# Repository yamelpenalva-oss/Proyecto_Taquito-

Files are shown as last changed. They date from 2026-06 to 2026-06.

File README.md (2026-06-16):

# Robot Futbolista Autónomo

---

## Institución

Escuela de Educación Secundaria Técnica N° 5  
“2 de Abril” – Temperley – Buenos Aires

---

## Materia

Montajes de Proyectos Electrónicos

---

## Grupo

Taquito

---

## Autores

Nuñez, Ian — naikalo2000@gmail.com  
Guerra, Marcos — marcoscolegio3@gmail.com  
Penalva, Yamel — yamelpenalva@gmail.com  

---

## Profesor

Ing. Martín Leguizamón

---

## Descripción del proyecto

El presente proyecto consiste en el desarrollo de un robot futbolista autónomo, diseñado para participar en ligas nacionales de robótica.

El sistema integra hardware y software para permitir un comportamiento autónomo capaz de interactuar con el entorno en tiempo real, mediante la detección de la pelota, posicionamiento en el campo de juego y toma de decisiones.

El control del robot se realiza a través de microcontroladores ESP32 programados , aplicando principios de programación embebida.

---

## Objetivos

- Desarrollar un robot autónomo orientado a competencias de fútbol robótico  
- Integrar sensores, actuadores y microcontroladores  
- Implementar lógica de control en tiempo real  
- Aplicar conocimientos de electrónica y programación  
- Lograr un sistema funcional y eficiente  

---

## Materiales utilizados

- Motores de corriente continua (x4)  
- Módulo WiFi/Bluetooth  
- Microcontroladores ESP32 (x2)  
- Controladores de motor (TN6612 o TA6586)  

---

## Tecnologías y herramientas

- Lenguaje: C++ (framework Arduino / ESP32)  
- Entorno de desarrollo: Arduino IDE  
- Comunicación: WiFi y Bluetooth  
- Control de motores mediante PWM  
- Lectura de sensores digitales y analógicos  

---

## Lógica del sistema

El funcionamiento del robot se basa en una arquitectura de control que incluye:

- Lectura continua de sensores  
- Procesamiento de datos en tiempo real  
- Toma de decisiones mediante estructuras condicionales  
- Control de actuadores en función del entorno  

El comportamiento general contempla estrategias de búsqueda, ataque y corrección de trayectoria.

---

## Funcionamiento

El firmware desarrollado permite:

- Controlar el movimiento del robot  
- Procesar información del entorno  
- Ejecutar estrategias de juego  
- Adaptarse a condiciones variables durante la competencia  

El código se encuentra estructurado de forma modular, facilitando su mantenimiento y escalabilidad.

---

## Estado del proyecto

- Sistema funcional  
- Integración de hardware completa  
- Control de motores implementado  
- Proyecto en mejora continua  

---

## Mejoras futuras

- Optimización del sistema de detección de pelota  
- Mejora en la precisión de movimiento  
- Implementación de comunicación entre módulos  
- Desarrollo de estrategias más avanzadas  

---

## Enfoque de ingeniería

El proyecto fue desarrollado con un enfoque práctico, orientado a su implementación en entornos reales de competencia, priorizando:

- Robustez del sistema  
- Simplicidad en la lógica de control  
- Eficiencia en el uso de recursos  
- Claridad en la estructura del código  

---

## preguntas 

-Ante cualquier consulta o inconveniente, comuníquese con Yamel Penalva a través de Gmail.

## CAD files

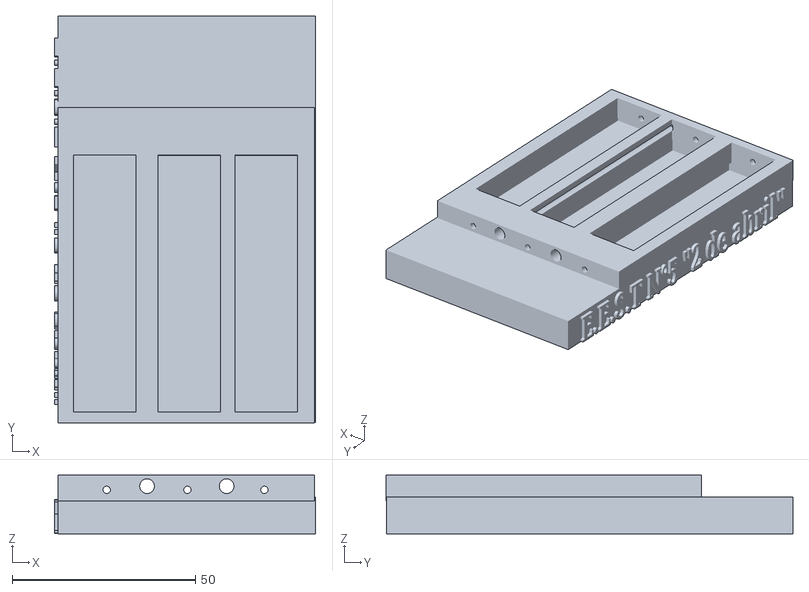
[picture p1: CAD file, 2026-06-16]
diseño3D/porta pilas.stl
71.3 x 111.0 x 16.0

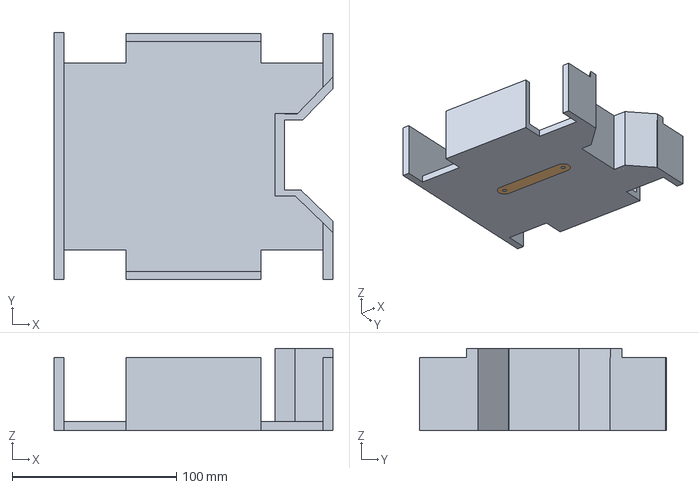
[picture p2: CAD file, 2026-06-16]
diseño3D/futbolista diseño 3d.3mf
170.0 x 150.5 x 50.0 mm
Futbolista Seba.stl_1
Futbolista Seba.stl_2

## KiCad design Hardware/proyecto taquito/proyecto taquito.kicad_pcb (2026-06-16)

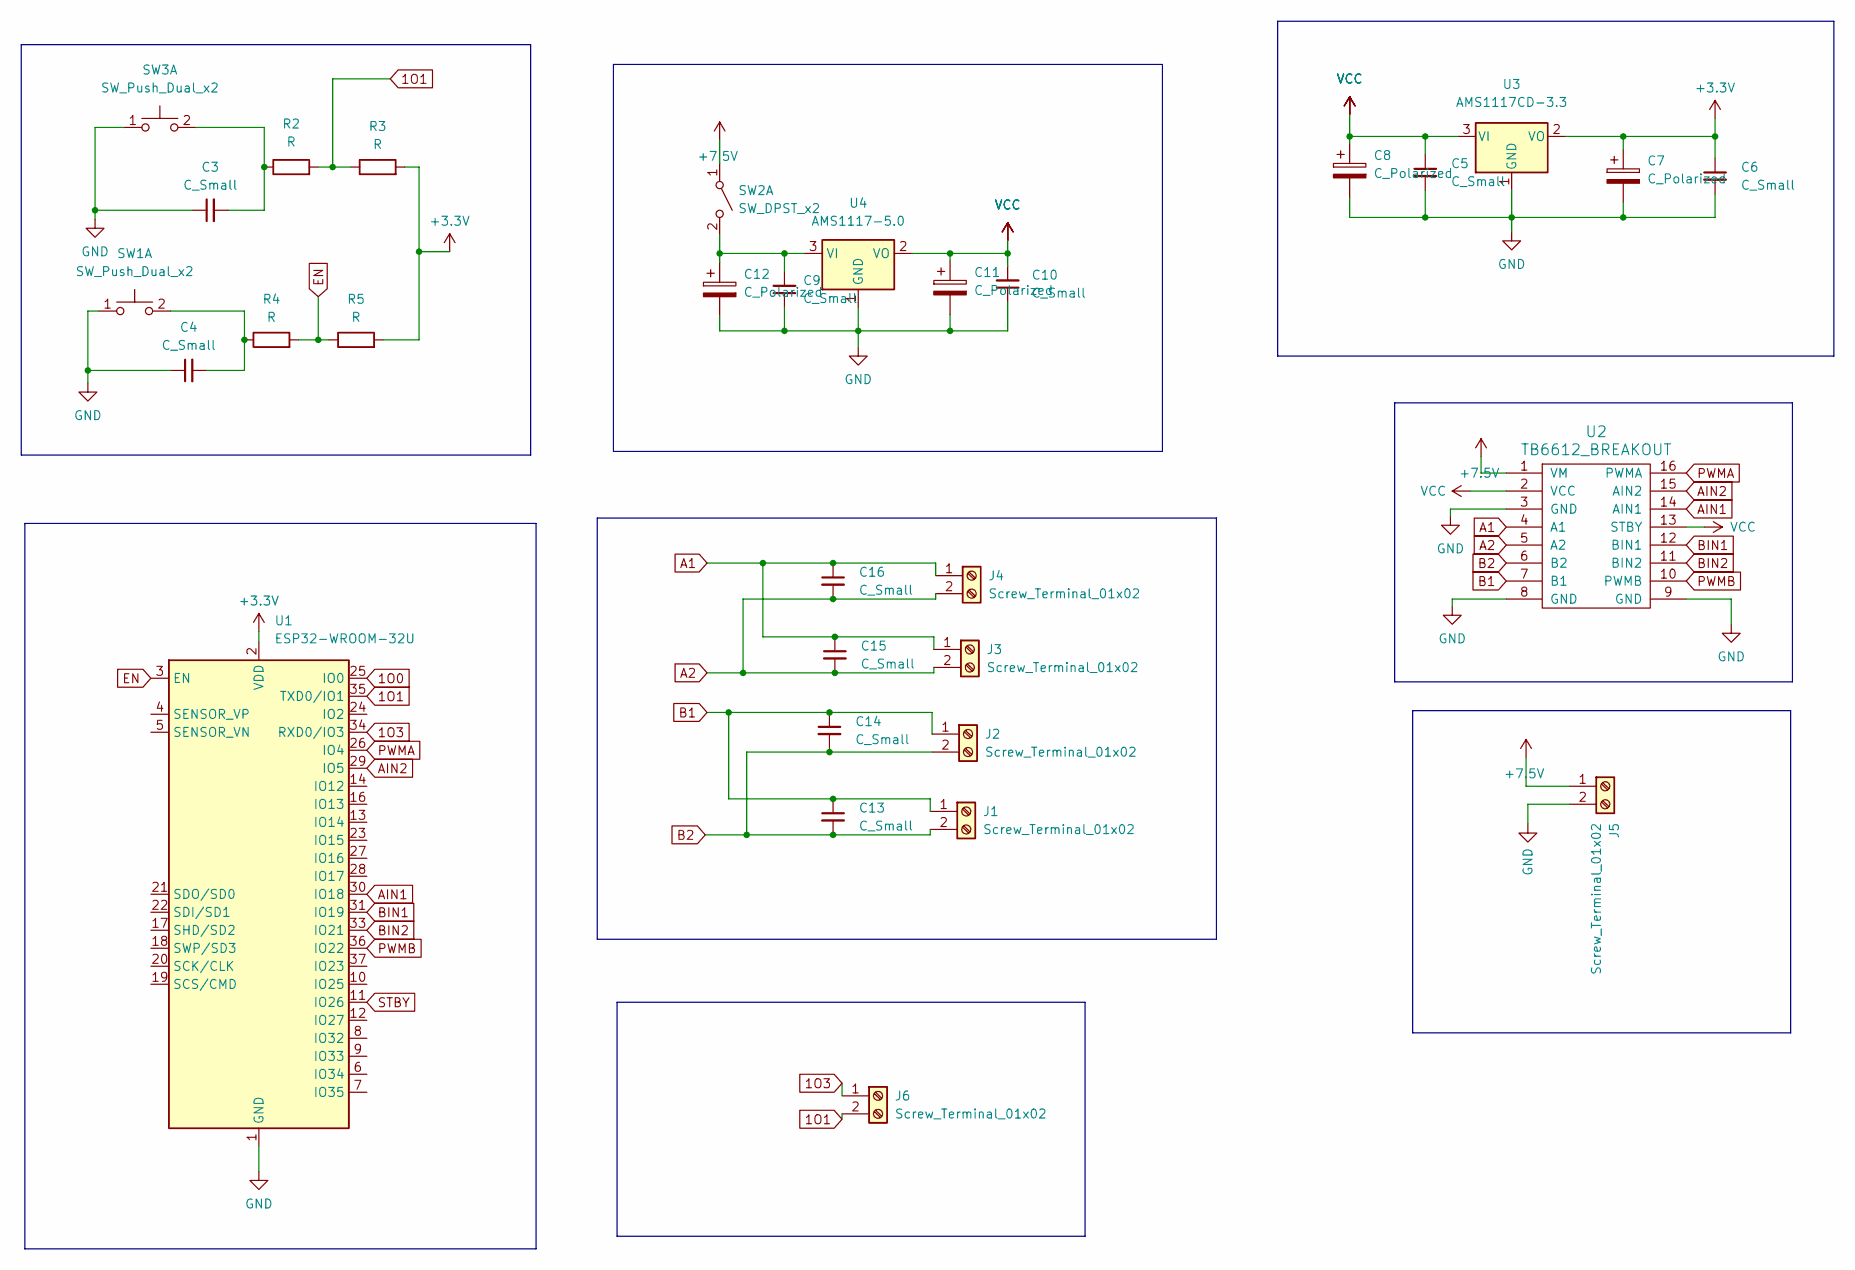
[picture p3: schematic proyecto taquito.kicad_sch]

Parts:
C3, C4, C5, C6, C9, C10: C_Small; R_0805_2012Metric_Pad1.20x1.40mm_HandSolder
C7, C8, C11, C12: C_Polarized; R_0805_2012Metric_Pad1.20x1.40mm_HandSolder
C13, C14, C15, C16: C_Small; C_Disc_D3.0mm_W1.6mm_P2.50mm
J1, J2, J3, J4, J5: Screw_Terminal_01x02; TerminalBlock_MaiXu_MX126-5.0-02P_1x02_P5.00mm
J6: Screw_Terminal_01x02; PinHeader_1x02_P2.54mm_Vertical
R2, R3, R4, R5: R; R_0805_2012Metric
SW1, SW3: SW_Push_Dual_x2; SW_PUSH_6mm
SW2: SW_DPST_x2; SW_ATE1D-2M3-10-Z
U1: ESP32-WROOM-32U
U2: TB6612_BREAKOUT; MODULE_ROB-14450
U3: AMS1117CD-3.3; SOT-223-3_TabPin2
U4: AMS1117-5.0; SOT-223-3_TabPin2

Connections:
1O0: U1.25 (IO0)
1O1: J6.2, R2.2, R3.1, U1.35 (TXD0/IO1)
1O3: J6.1, U1.34 (RXD0/IO3)
+3.3V: C6.1, C7.1, R3.2, R5.2, U1.2 (VDD), U3.2 (VO)
+7.5V: J5.1, SW2.1 (A), U2.1 (VM)
A1: C15.1, C16.1, J3.1, J4.1, U2.4 (A1)
A2: C15.2, C16.2, J3.2, J4.2, U2.5 (A2)
AIN1: U1.30 (IO18), U2.14 (AIN1)
AIN2: U1.29 (IO5), U2.15 (AIN2)
B1: C13.1, C14.1, J1.1, J2.1, U2.7 (B1)
B2: C13.2, C14.2, J1.2, J2.2, U2.6 (B2)
BIN1: U1.31 (IO19), U2.12 (BIN1)
BIN2: U1.33 (IO21), U2.11 (BIN2)
EN: R4.2, R5.1, U1.3 (EN)
GND: C3.1, C4.1, C5.2, C6.2, C7.2, C8.2, C9.1, C10.1, C11.2, C12.2, J5.2, SW1.1 (C), SW3.1 (C), U1.1 (GND), U1.15 (GND), U1.38 (GND), U1.39 (GND), U2.3 (GND), U2.8 (GND), U2.9 (GND), U3.1 (GND), U4.1 (GND)
unnamed: C4.2, R4.1, SW1.2 (D)
unnamed: C9.2, C12.1, SW2.2 (B), U4.3 (VI)
unnamed: C3.2, R2.1, SW3.2 (D)
PWMA: U1.26 (IO4), U2.16 (PWMA)
PWMB: U1.36 (IO22), U2.10 (PWMB)
STBY: U1.11 (IO26)
VCC: C5.1, C8.1, C10.2, C11.1, U2.2 (VCC), U2.13 (STBY), U3.3 (VI), U4.2 (VO)

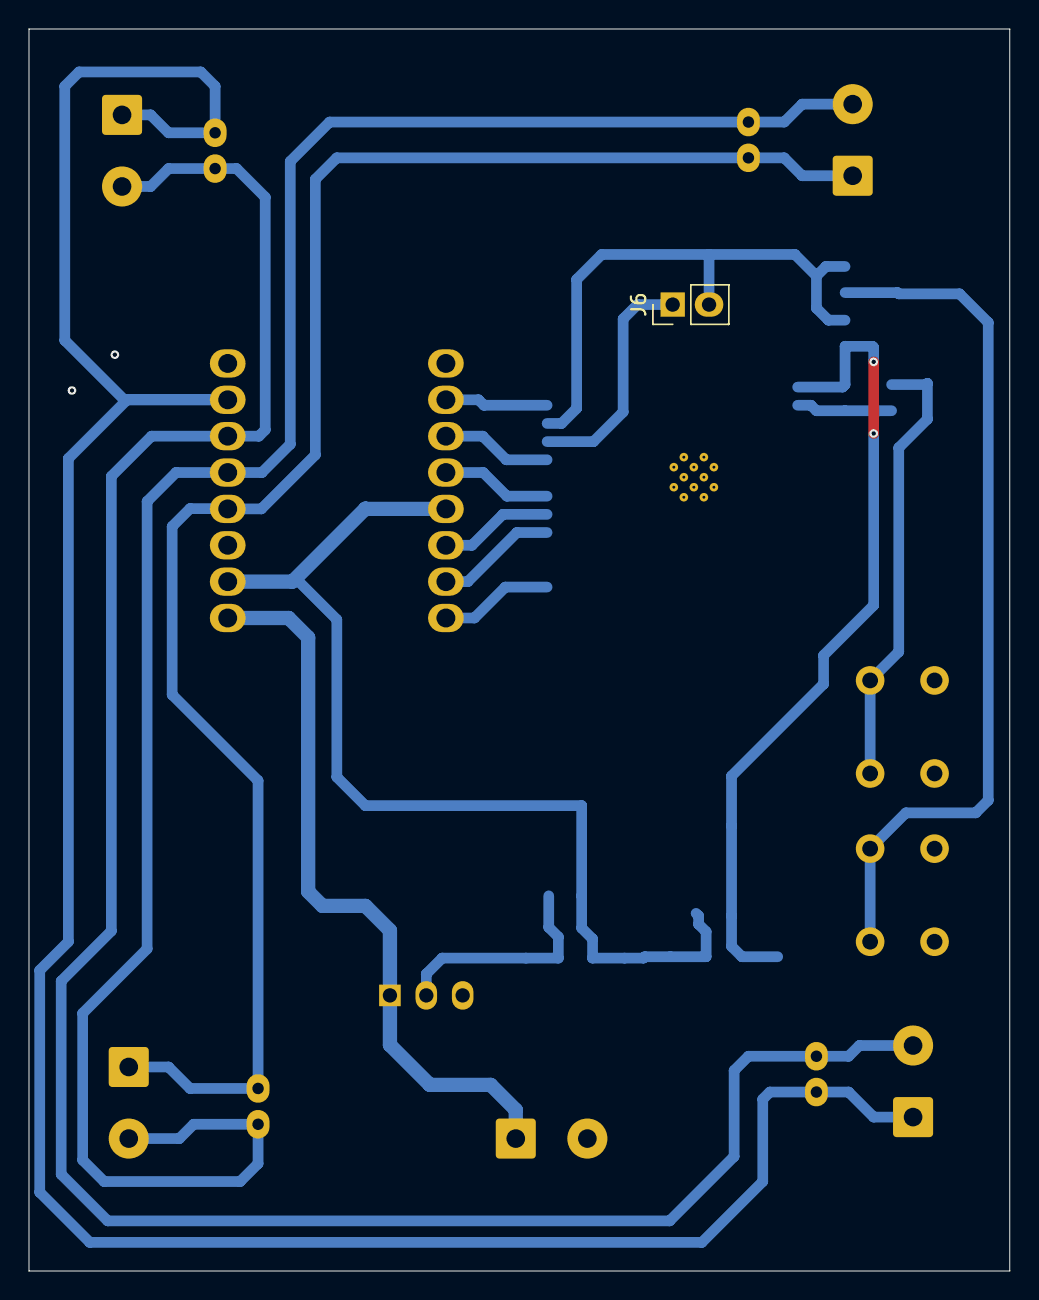
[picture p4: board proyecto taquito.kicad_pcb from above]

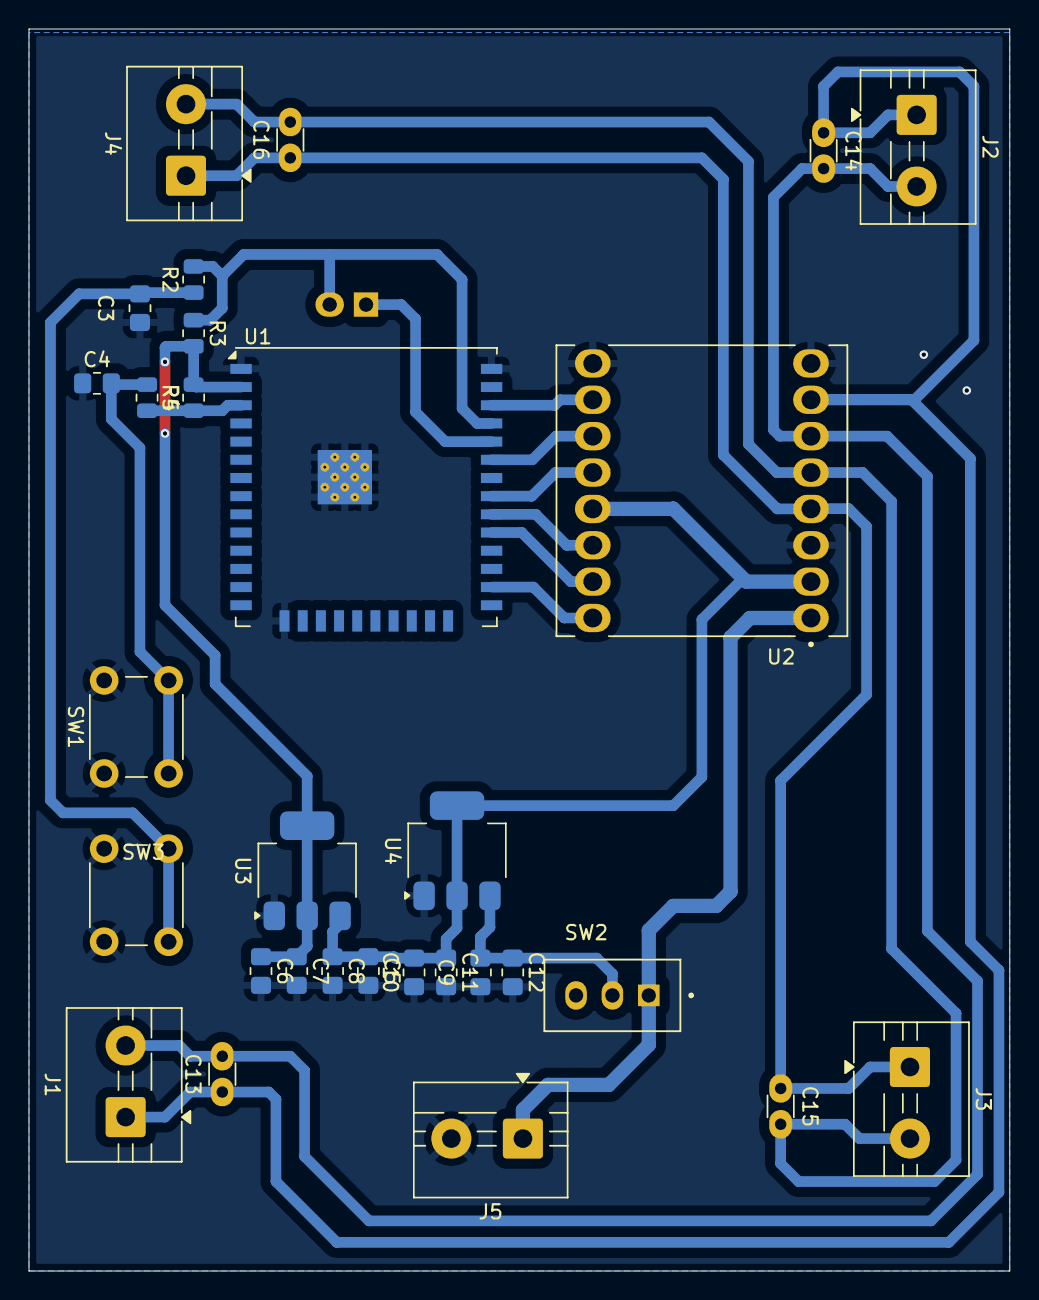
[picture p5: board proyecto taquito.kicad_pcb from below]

Board: 2 copper layers, 68.5 x 86.8 mm, 31 parts (30 on the bottom side), 20 nets.

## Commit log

2026-06-09 9/6 16:12
    [mecagoentodotio.kicad_pcb]
2026-06-19 19/6 cumple de barzola
    [proyecto taquito.kicad_pcb, proyecto taquito.kicad_sch]
